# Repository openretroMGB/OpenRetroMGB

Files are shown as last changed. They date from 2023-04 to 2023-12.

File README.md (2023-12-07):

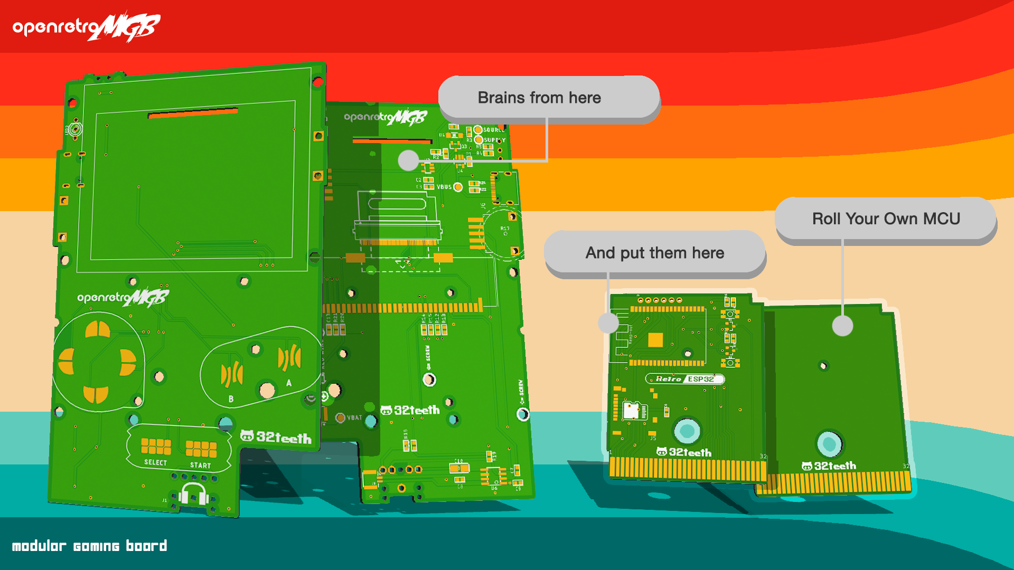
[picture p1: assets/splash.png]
Splash

> Get ready to elevate your retro gaming experience with **OpenretroMGB** - the open-source, modular gaming board that lets you customize your gameplay. Our upcoming campaign will offer exclusive rewards and perks, so don't miss out on your chance to join the retro gaming revolution. Stay tuned for more details and be part of the community that's bringing back the best of the past with the power of the future!

## Overview

**OpenretroMGB** is a new open-source ***M***odular ***G***aming ***B***oard designed for gamers and hobbyists alike. Based on the popular Retro ESP32, this compact and portable board is compatible with Game Boy Pocket form factor and allows customers to either use the prebuilt ESP32 cartridge or design their own. With an easy-to-use modular design, gamers can customize their gaming experience by swapping out cartridges that feature different games or hardware functionalities. OpenretroMGB offers an affordable and accessible way to create and enjoy retro-style games with modern features, making it perfect for enthusiasts, hobbyists, and anyone looking for a fun, retro gaming experience.

**OpenretroMGB** is certified unde Open Source Hardware as OSHWA UID [CA000028](https://certification.oshwa.org/ca000028.html) with CC-BY-SA-4.0 licensing

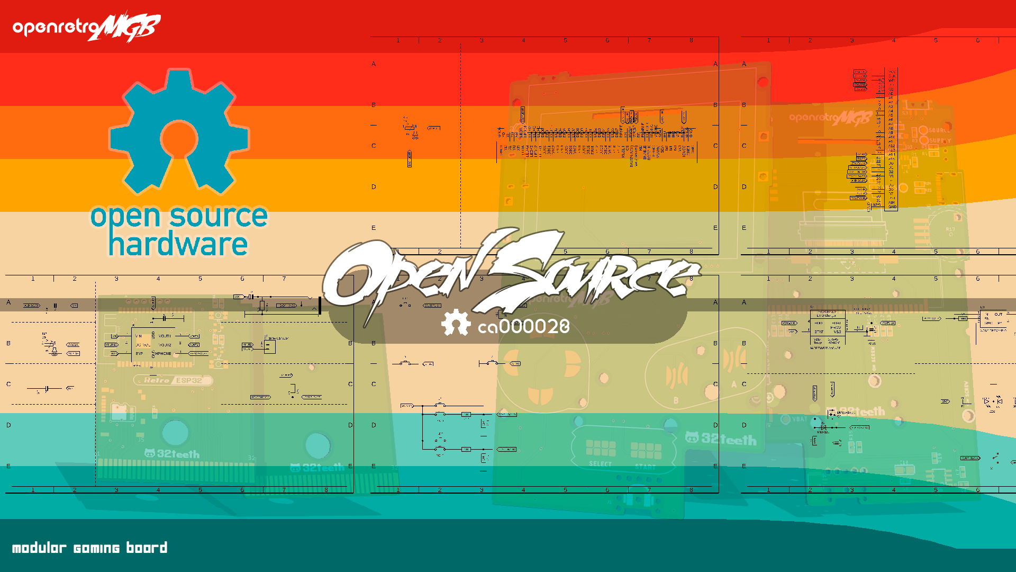
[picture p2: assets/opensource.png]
Open Source


## Features
- [x] Cartridge slot
- [x] 2.6" daylight IPS screen
- [x] Volume and brightness control
- [x] LiPo battery charging and protection circuitry
- [x] Stereo chip and headphone jack
- [x] Drop-in compatibility with Game Boy Pocket shell
- [x] Modular design
- [x] USB Data Lines
- [x] Open source

### Have your say

Join our discussions. Cast your vote in our [polls](https://github.com/openretroMGB/OpenRetroMGB/discussions/categories/polls)

## Gallery

#### Retro ESP32 Cart
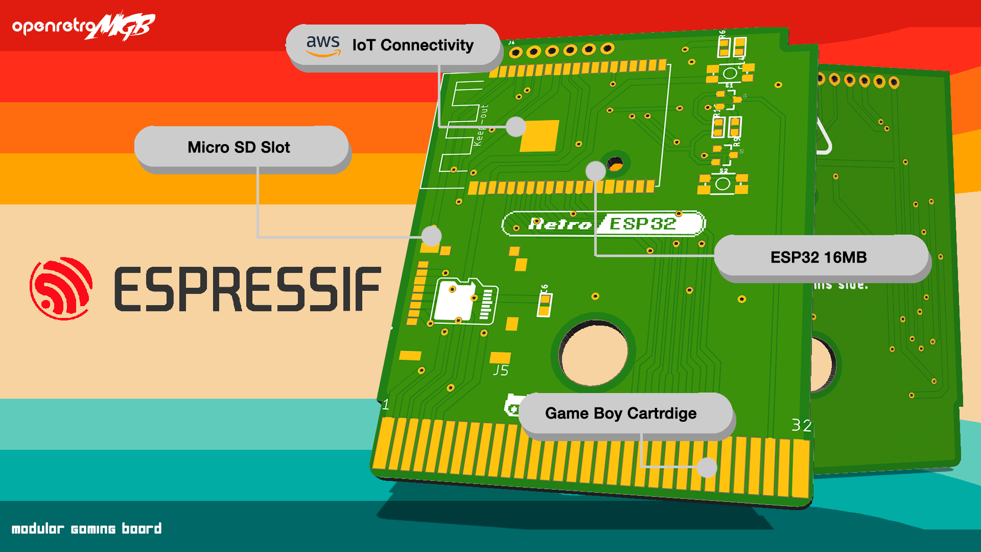
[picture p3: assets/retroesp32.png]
Retro ESP32


#### Arduino *ATmega32U4* Cart
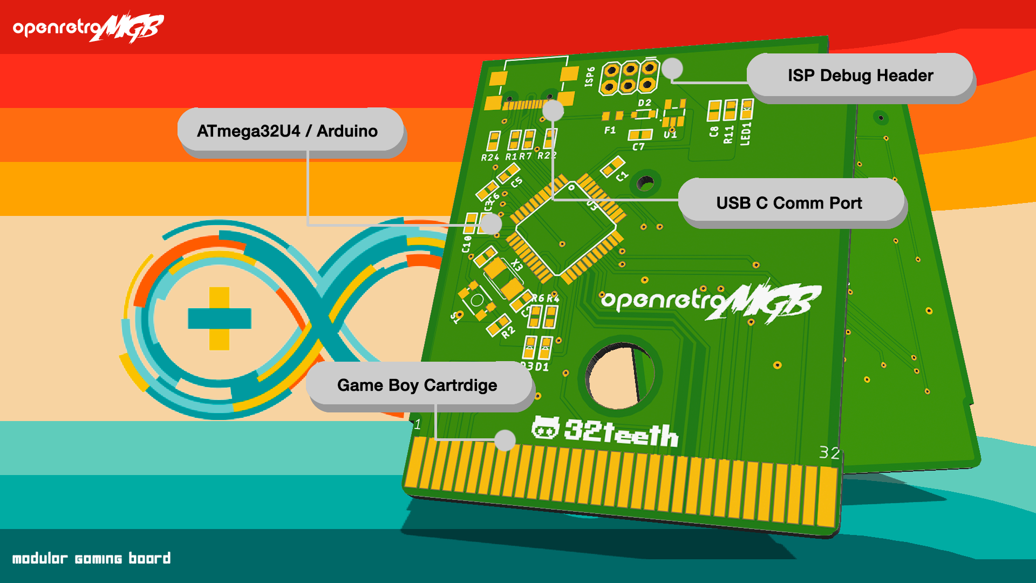
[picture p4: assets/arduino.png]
Arduino


#### USB C Data Lines
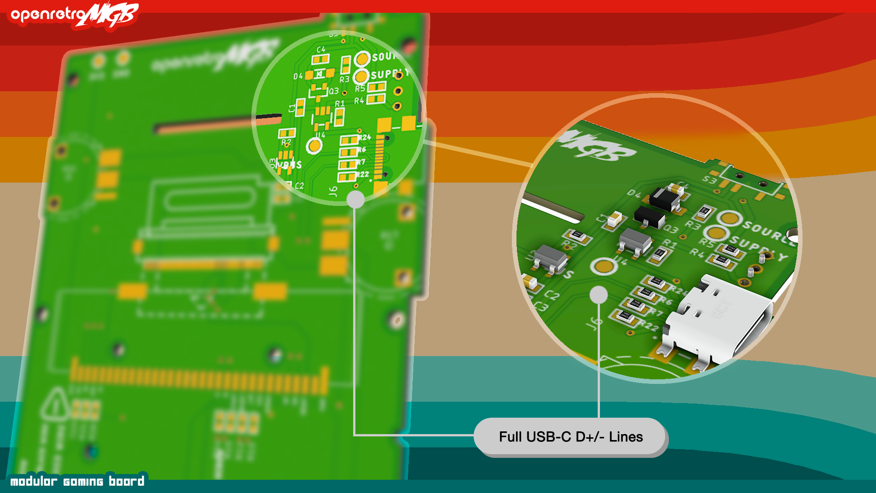
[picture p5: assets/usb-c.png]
USB


# What will you build?
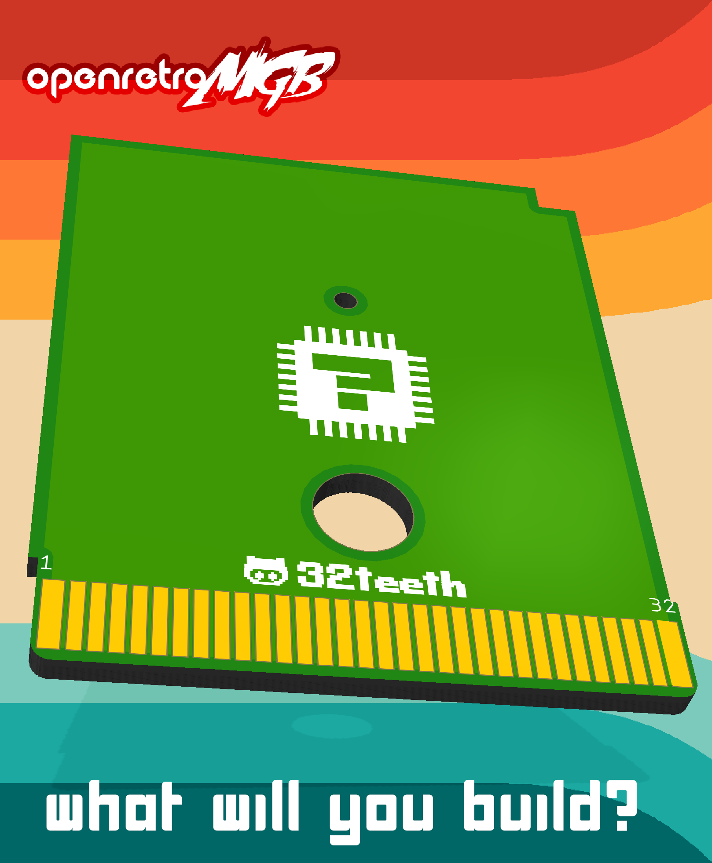
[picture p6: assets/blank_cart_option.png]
What will you build?


## Trusted Creators
> Celebrating 10 Years

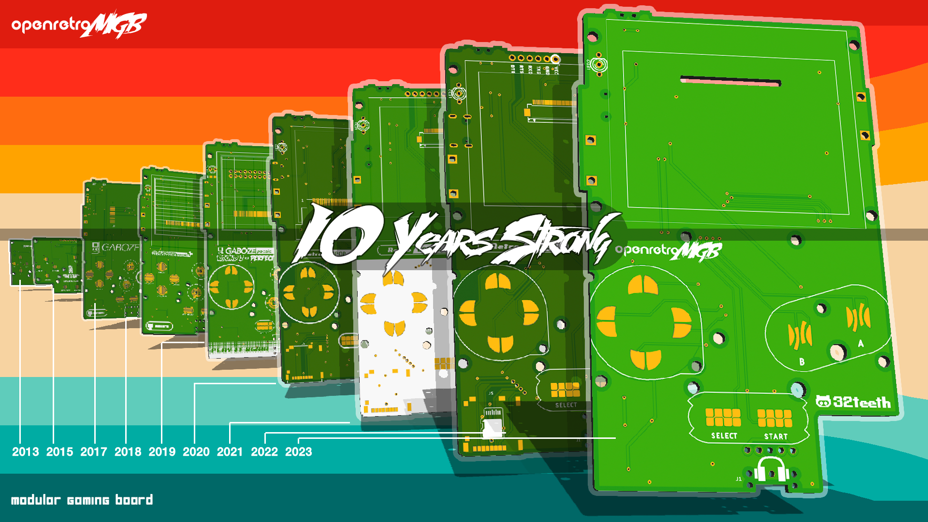
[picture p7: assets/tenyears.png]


Over the past 10 years, we have proudly established ourselves as a trusted creator and innovator in the realm of handheld retro gaming. From our early ventures with Arduino and Atmega microcontrollers to our exploration of cutting-edge technologies like ESP32 and Raspberry Pi, our journey has been driven by a relentless pursuit of innovation. With each step, we have strived to enhance the gaming experience for retro enthusiasts. Our Game Boy Pocket PCB embodies our dedication to quality, reliability, and creativity. It represents a culmination of years of expertise, resulting in a product that seamlessly blends the nostalgia of classic gaming with the power and possibilities of modern technology. As we celebrate this milestone, we extend our gratitude to our loyal customers and supporters, who have played an instrumental role in our growth and success. Looking ahead, we remain committed to pushing boundaries, embracing new advancements, and delivering unforgettable gaming experiences to enthusiasts around the world.

## Authors

* **Eugene Yevhen Andruszczenko** - *Initial and Ongoing Work* - [32teeth](https://github.com/32teeth)

### License

This project is licensed under the Creative Commons Attribution Share Alike 4.0 International - see the [LICENSE.md](LICENSE.md) file for details

## Support
> Although we do this for 💕 of 🕹️<br/>
> **We Also Like Coffee!** <br/>
> *Please Consider Supporting* <br/>

Did you know, you can support us in a few way? We offer multiple sposorship tiers, with different rewards!

Take a *look*.
See what *fits*.

 Support (https://github.com/sponsors/openretroMGB)

**Thank You**

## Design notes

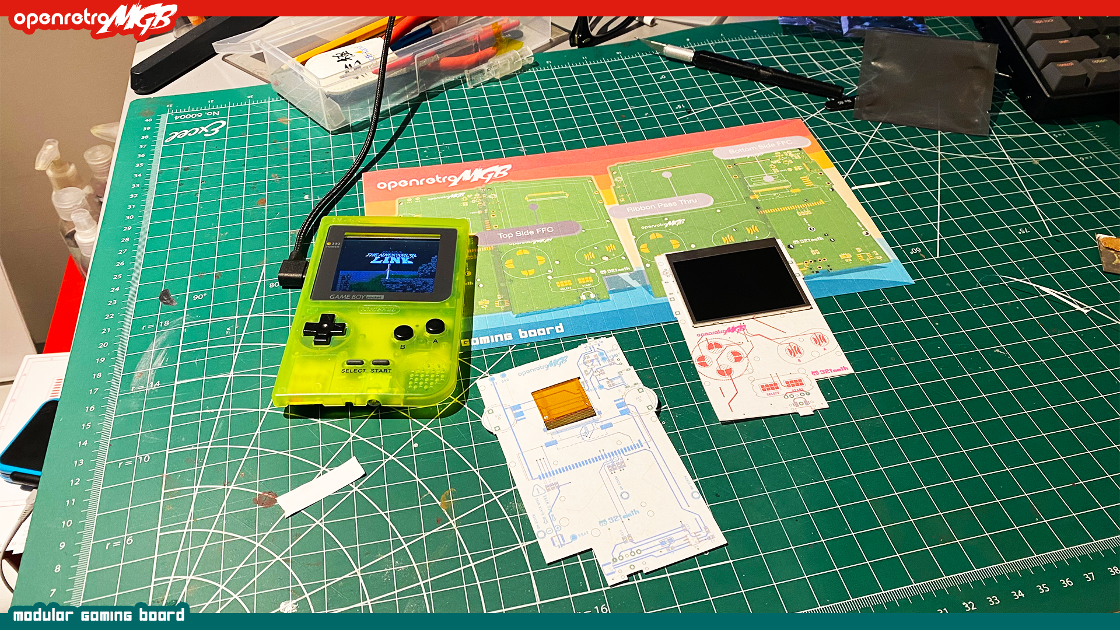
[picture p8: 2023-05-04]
assets/paper.png

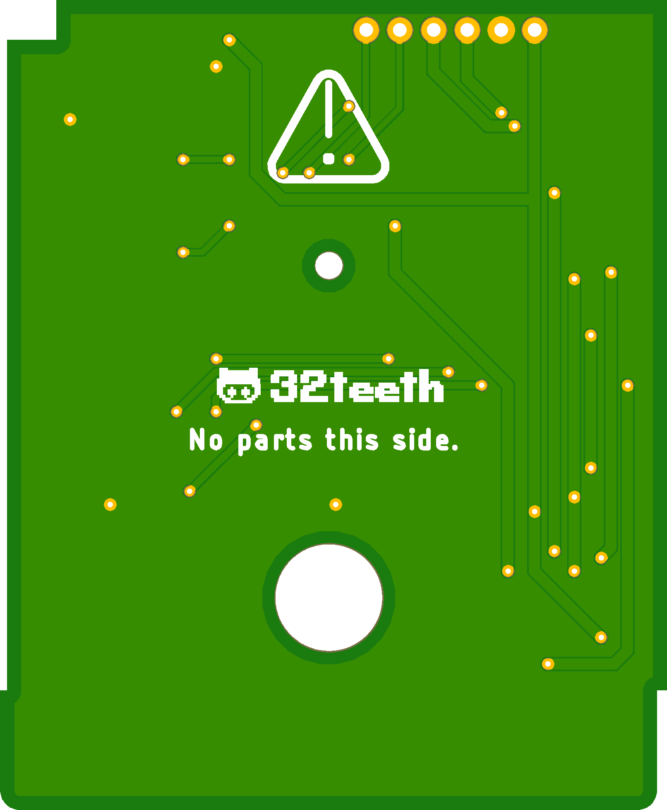
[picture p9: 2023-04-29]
assets/retro_cart_bottom.png

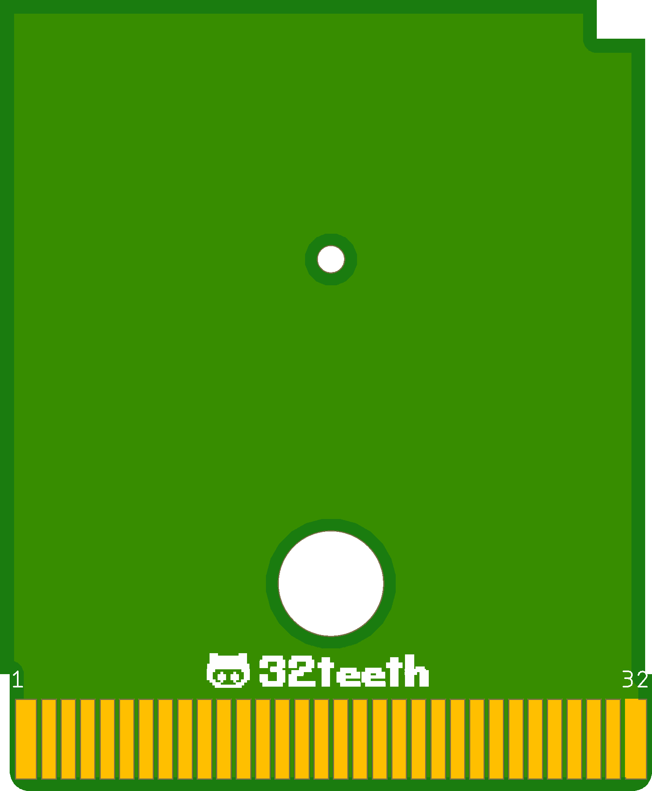
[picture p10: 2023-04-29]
assets/blank_cart_top.png

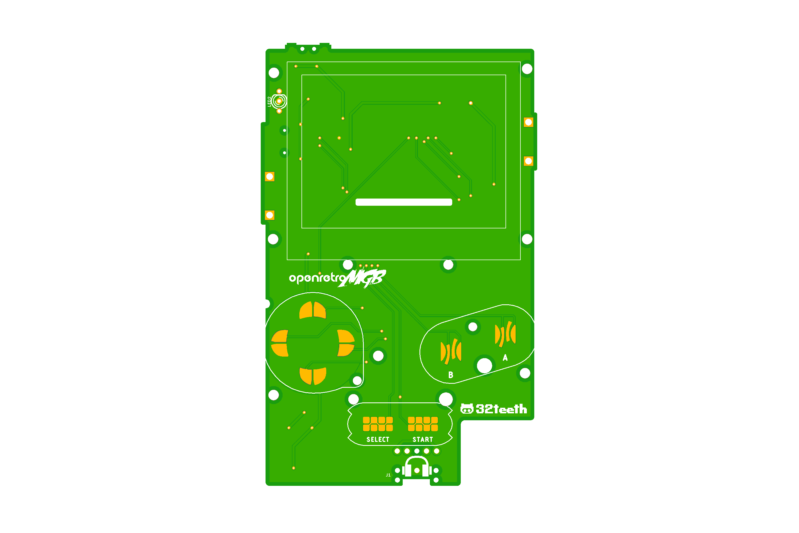
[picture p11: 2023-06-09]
assets/mainboard_new_top.png

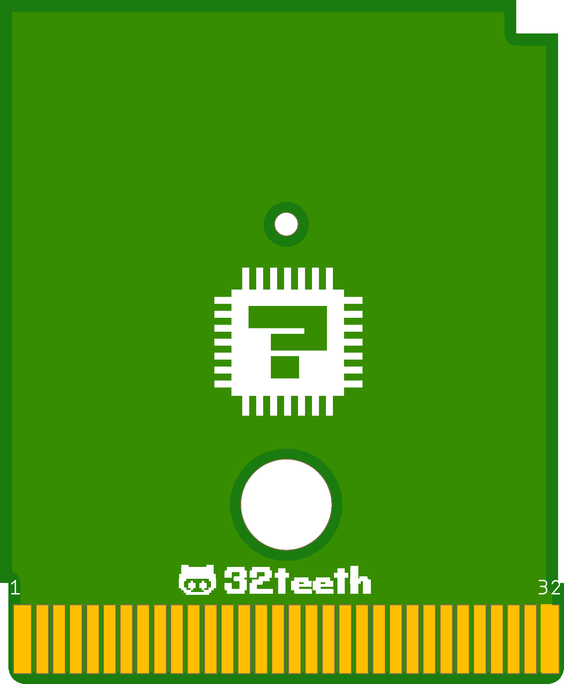
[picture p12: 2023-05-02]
assets/blank_cart_top_next.png

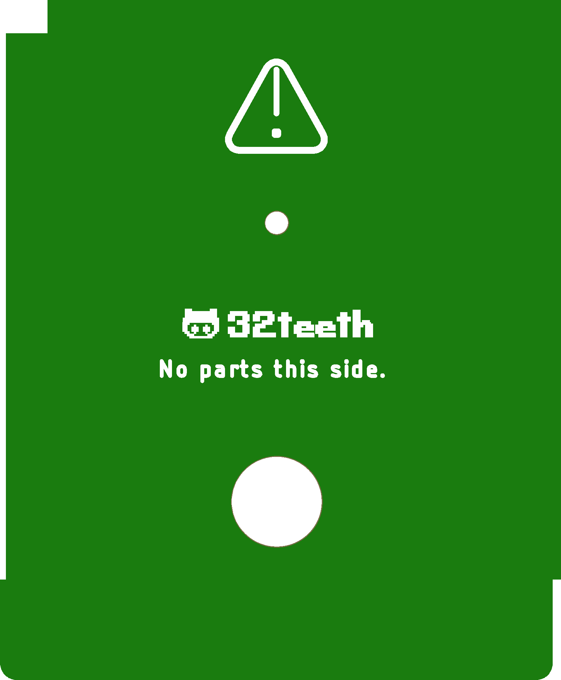
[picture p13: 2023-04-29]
assets/blank_cart_bottom.png

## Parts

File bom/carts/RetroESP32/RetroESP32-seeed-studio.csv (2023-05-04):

Qty | Designator | Package | MPN | Purchase Link
3 | R6, R9, R10 | 0603-MINI | ERJ-PA3J103V | https://www.digikey.ca/en/products/detail/panasonic-electronic-components/ERJ-PA3J103V
1 | C6 | 0603-MINI-CAP | CL10A106MP8NNNC | https://www.digikey.ca/en/products/detail/samsung-electro-mechanics/CL10A106MP8NNNC/3887529
1 | C14 | 0603-MINI-CAP | CL10A105KP8NNNC | https://www.digikey.ca/en/products/detail/samsung-electro-mechanics/CL10A105KP8NNNC/3889268
1 | J5 | 503182-1852_MOLEX_503182-1852 | 5031821852 | https://www.digikey.ca/en/products/detail/molex/5031821852/5823232
1 | U1 | ESP32-WROVER_ESP32-WROVER | ESP32-WROVER-E-N16R8 | https://www.digikey.ca/en/products/detail/espressif-systems/ESP32-WROVER-E-N16R8/11613147
2 | S1, S2 | SWITCHES_TACTILE_SWITCH_SMD_4.6X2.8MM | KMR221GLFS | https://www.digikey.ca/en/products/detail/c-k/KMR221GLFS/550472?s=N4IgTCBcDaINIFkBKYwEYDiAZAYgZRAF0BfIA
2 | Q4, Q5 | SOT23-3 | MMBT2222A-7-F | https://www.digikey.ca/en/products/detail/diodes-incorporated/MMBT2222A-7-F/814503

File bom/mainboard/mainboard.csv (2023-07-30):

Qty | Designator | Package | MPN | Purchase Link | Notes
1 | C13 | 0603-MINI-CAP | CL10B104KB8NNNC | https://www.digikey.com/en/products/detail/samsung-electro-mechanics/CL10B104KB8NNNC/3886658
5 | R2, R3, R19, R20, R21 | 0603-MINI | ERJ-PA3J104V | https://www.digikey.com/en/products/detail/panasonic-electronic-components/ERJ-PA3J104V/5035972
1 | C10 | EIA3216-18/A-W | F930J107KAA | https://www.digikey.com/en/products/detail/kyocera-avx/F930J107KAA/4005275
5 | R11, R12, R13, R14, R15 | 0603-MINI | ERJ-PA3J103V | https://www.digikey.com/en/products/detail/panasonic-electronic-components/ERJ-PA3J103V/5035971
3 | C1, C2, C4 | 0603-MINI-CAP | CL10A106MP8NNNC | https://www.digikey.com/en/products/detail/samsung-electro-mechanics/CL10A106MP8NNNC/3887529
1 | R18 | 0603-MINI | ERJ-PA3J151V | https://www.digikey.com/en/products/detail/panasonic-electronic-components/erj-p03j151v/9810793
2 | R1, R5 | 0603-MINI | ERJ-PA3J152V | https://www.digikey.com/en/products/detail/panasonic-electronic-components/erj-p03j152v/9810794
3 | C3, C8, C9 | 0603-MINI-CAP | CL10A105KP8NNNC | https://www.digikey.com/en/products/detail/samsung-electro-mechanics/CL10A105KP8NNNC/3886840
1 | C7 | 0603-MINI-CAP | CL10C221JB8NFNC | https://www.digikey.com/en/products/detail/samsung-electro-mechanics/CL10C221JB8NFNC/3890321
2 | R16, R17 | THUMBWHEEL |  | https://www.aliexpress.com/item/1005005013077311.html | Alternate: https://www.aliexpress.com/item/1005004274957084.html
1 | R4 | 0603-MINI | CRGH0603J470R | https://www.digikey.com/en/products/detail/te-connectivity-passive-product/CRGH0603J470R/2385347
2 | R6, R7 | 0603-MINI | ERJ-3EKF22R0V | https://www.digikey.ca/en/products/detail/panasonic-electronic-components/ERJ-3EKF22R0V/1746340
2 | R22, R24 | 0603-MINI | ERJ-3EKF5111V | https://www.digikey.ca/en/products/detail/panasonic-electronic-components/ERJ-3EKF5111V/198416
1 | J1 | AUDIO-JACK-KIT | SJ1-3525NG | https://www.digikey.com/en/products/detail/cui-devices/SJ1-3525NG/738690
1 | Q3 | SOT23-R | DMP2045U-7 | https://www.digikey.com/en/products/detail/diodes-incorporated/DMP2045U-7/8275359
1 | U$2 | GB-CARTRIDGE-SLOT-2 |  | https://www.aliexpress.com/item/1005004188119429.html
1 | U$11 | KD026LQTMA008-PASSTHRU | 0541044531 | https://www.digikey.ca/en/products/detail/molex/0541044531/3197022
1 | LED2 | LED_DUOLED-A-3MM | SSL-LX3059IGW | https://www.digikey.com/en/products/detail/lumex-opto-components-inc/SSL-LX3059IGW/242268
1 | U6 | SOIC8 | LM4875MX/NOPB | https://www.digikey.com/en/products/detail/texas-instruments/LM4875MX-NOPB/1871686
1 | D4 | SOD-123 | MBRX120LF-TP | digikey.com/en/products/detail/micro-commercial-co/MBRX120LF-TP/2041570
1 | U4 | SOT23-5-1 | MCP73832T-2ACI/OT | https://www.digikey.com/en/products/detail/microchip-technology/mcp73832t-2aci-ot/1223142
1 | S3 | RETIRED_KPS-1290 | MA12RTR | https://www.digikey.com/en/products/detail/apem-inc/MA12RTR
2 | X2, X3 | 53261-02 | 0532614002 | https://www.digikey.ca/en/products/detail/molex/0532614002/15622958
1 | J6 | GCT_USB4110-GF-A_REVB | USB4110-GF-A | https://www.digikey.ca/en/products/detail/gct/usb4110-gf-a/10384547
1 | U3 | SOT23-5 | XC6210B332MR-G | https://www.digikey.ca/en/products/detail/torex-semiconductor-ltd/XC6210B332MR-G/2138119
1 | N/A - This is the LCD itself |  | ET026LQTM008 | https://www.alibaba.com/product-detail/Support-Small-Quantity-2-6-inch_1600609986142.html | Alternate: https://www.aliexpress.com/item/4001077459037.html

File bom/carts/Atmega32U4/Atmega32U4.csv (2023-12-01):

Qty | Designator | Package | MPN | Purchase Link
2 | C1, C3 | 0603-MINI | CL10B104KB8NNNC | https://www.digikey.ca/en/products/detail/samsung-electro-mechanics/CL10B104KB8NNNC/3886658
3 | C5, C6, C10 | 0603-MINI-CAP | CL10A105KP8NNNC | https://www.digikey.ca/en/products/detail/samsung-electro-mechanics/CL10A105KP8NNNC/3886840
1 | R2 | 0603-MINI | ERJ-PA3J103V | https://www.digikey.ca/en/products/detail/panasonic-electronic-components/ERJ-PA3J103V/5035971
2 | C7, C8 | 0603-MINI-CAP | CL10A106MP8NNNC | https://www.digikey.ca/en/products/detail/samsung-electro-mechanics/CL10A106MP8NNNC/3887529
1 | X3 | NX5032 | NX5032GA-16.000000MHZ-LN-CD-1 | https://www.digikey.ca/en/products/detail/ndk-america-inc/NX5032GA-16-000000MHZ-LN-CD-1/1128819
3 | R4, R6, R11 | 0603-MINI | CRGH0603J1K0 | https://www.digikey.ca/en/products/detail/te-connectivity-passive-product/CRGH0603J1K0/2385355
2 | C2, C4 | 0603-MINI-CAP | CL10C220JB81PNC | https://www.digikey.ca/en/products/detail/samsung-electro-mechanics/CL10C220JB81PNC/3887884
1 | U1 | SOT23-5 | AP2112K-3.3TRG1 | https://www.digikey.ca/en/products/detail/diodes-incorporated/AP2112K-3-3TRG1/4470746
1 | U3 | TQFP44 | ATMEGA32U4RC-AU | https://www.digikey.ca/en/products/detail/microchip-technology/ATMEGA32U4RC-AU/2507982
1 | D2 | SOD-323 | PMEG1030EJ,115 | https://www.digikey.ca/en/products/detail/nexperia-usa-inc/PMEG1030EJ-115/1157660
2 | R1, R7 | 0603-MINI | ERJ-3EKF22R0V | https://www.digikey.ca/en/products/detail/panasonic-electronic-components/ERJ-3EKF22R0V/1746340
2 | R22, R24 | 0603-MINI | ERJ-PA3F5101V | https://www.digikey.ca/en/products/detail/panasonic-electronic-components/ERJ-PA3F5101V/5035934
1 | F1 | 1206 | PTS12066V050 | https://www.digikey.ca/en/products/detail/eaton-electronics-division/PTS12066V050/2639136
3 | D1, D3, LED1 | CHIPLED_0603 | SML-LX0603GW-TR | https://www.digikey.ca/en/products/detail/lumex-opto-components-inc/SML-LX0603GW-TR/304359
1 | S1 | TACTILE_SWITCH_SMD_4.6X2.8MM | KMR221GLFS | https://www.digikey.ca/en/products/detail/c-k/KMR221GLFS/550472
1 | J6 | GCT_USB4110-GF-A_REVB | USB4110-GF-A | https://www.digikey.ca/en/products/detail/gct/USB4110-GF-A/10384547

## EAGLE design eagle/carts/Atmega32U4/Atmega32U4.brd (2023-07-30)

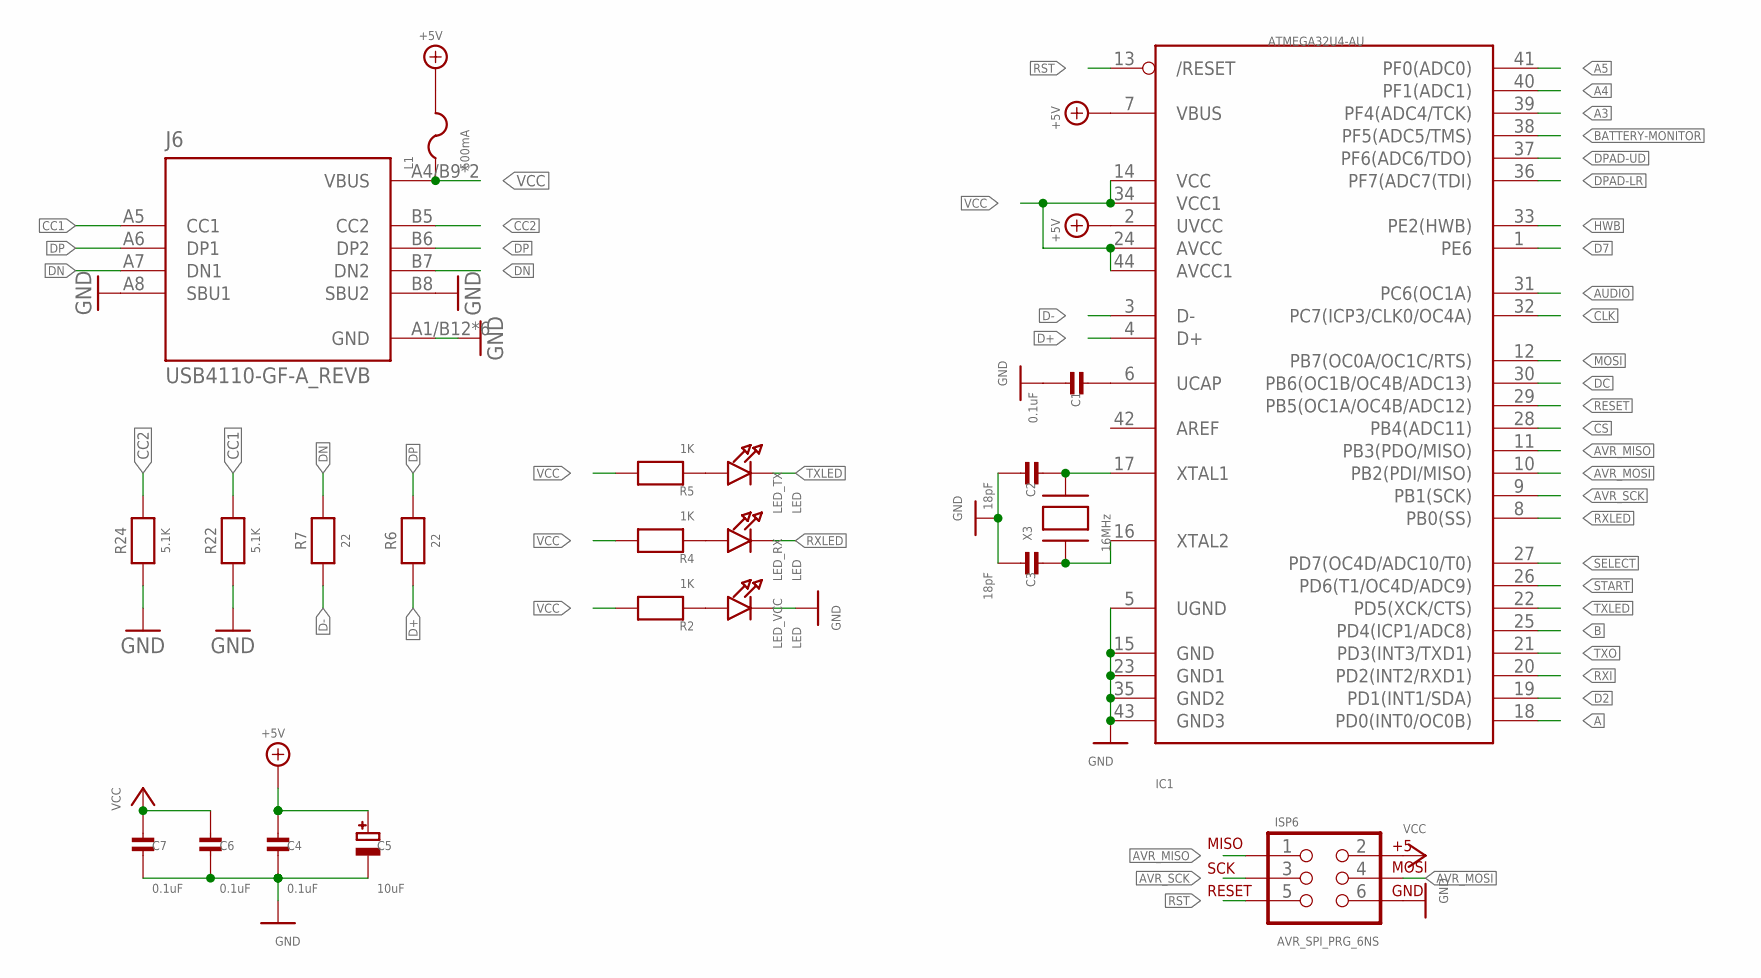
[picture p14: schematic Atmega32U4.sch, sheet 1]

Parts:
C1, C4, C6, C7: 0.1uF; 0603-MINI-CAP
C2, C3: 18pF; 0603-MINI-CAP
C5: 10uF; EIA3216-18/A-W
IC1: ATMEGA32U4-AU; TQFP44
ISP6: AVR_SPI_PRG_6NS; 2X3-NS
J6: USB4110-GF-A_REVB; GCT_USB4110-GF-A_REVB; MPN USB4105-GF-A
L1: 500mA; R1206
LED_RX: LED; CHIPLED_0603
LED_TX: LED; CHIPLED_0603
LED_VCC: LED; CHIPLED_0603
R2, R4, R5: 1K; 0603-MINI
R6, R7: 22; 0603-MINI; MPN ERJ-3EKF22R0V
R22, R24: 5.1K; 0603-MINI; MPN ERJ-PA3F5101V
X3: 16MHz; NX5032

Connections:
+5V: C4.1, C5.+, IC1.2 (UVCC), IC1.7 (VBUS), L1.2
A: IC1.18 (PD0(INT0/OC0B)); also elsewhere on the board
A3: IC1.39 (PF4(ADC4/TCK))
A4: IC1.40 (PF1(ADC1))
A5: IC1.41 (PF0(ADC0))
AUDIO: IC1.31 (PC6(OC1A)); also elsewhere on the board
AVR_MISO: IC1.11 (PB3(PDO/MISO)), ISP6.1
AVR_MOSI: IC1.10 (PB2(PDI/MISO)), ISP6.4
AVR_SCK: IC1.9 (PB1(SCK)), ISP6.3
B: IC1.25 (PD4(ICP1/ADC8)); also elsewhere on the board
BATTERY-MONITOR: IC1.38 (PF5(ADC5/TMS)); also elsewhere on the board
CC1: J6.A5 (CC1), R22.2
CC2: J6.B5 (CC2), R24.2
CLK: IC1.32 (PC7(ICP3/CLK0/OC4A)); also elsewhere on the board
CS: IC1.28 (PB4(ADC11)); also elsewhere on the board
D2: IC1.19 (PD1(INT1/SDA))
D7: IC1.1 (PE6)
D+: IC1.4 (D+), R6.1
D-: IC1.3 (D-), R7.1
DC: IC1.30 (PB6(OC1B/OC4B/ADC13)); also elsewhere on the board
DN: J6.A7 (DN1), J6.B7 (DN2), R7.2
DP: J6.A6 (DP1), J6.B6 (DP2), R6.2
DPAD-LR: IC1.36 (PF7(ADC7(TDI)); also elsewhere on the board
DPAD-UD: IC1.37 (PF6(ADC6/TDO)); also elsewhere on the board
GND: C1.2, C2.2, C3.2, C4.2, C5.-, C6.2, C7.2, IC1.5 (UGND), IC1.15 (GND), IC1.23 (GND1), IC1.35 (GND2), IC1.43 (GND3), ISP6.6, J6.A1/B12 (GND), J6.A8 (SBU1), J6.B1/A12 (GND), J6.B8 (SBU2), J6.S1 (GND), J6.S2 (GND), J6.S3 (GND), J6.S4 (GND), LED_VCC.C, R22.1, R24.1; also elsewhere on the board
HWB: IC1.33 (PE2(HWB))
MOSI: IC1.12 (PB7(OC0A/OC1C/RTS)); also elsewhere on the board
unnamed: LED_VCC.A, R2.1
unnamed: C1.1, IC1.6 (UCAP)
unnamed: LED_RX.A, R4.1
unnamed: LED_TX.A, R5.1
unnamed: C2.1, IC1.17 (XTAL1), X3.P$2
unnamed: C3.1, IC1.16 (XTAL2), X3.P$1
RESET: IC1.29 (PB5(OC1A/OC4B/ADC12)); also elsewhere on the board
RST: IC1.13 (/RESET), ISP6.5
RXI: IC1.20 (PD2(INT2/RXD1))
RXLED: IC1.8 (PB0(SS)), LED_RX.C
SELECT: IC1.27 (PD7(OC4D/ADC10/T0)); also elsewhere on the board
START: IC1.26 (PD6(T1/OC4D/ADC9)); also elsewhere on the board
TXLED: IC1.22 (PD5(XCK/CTS)), LED_TX.C
TXO: IC1.21 (PD3(INT3/TXD1))
VCC: C6.1, C7.1, IC1.14 (VCC), IC1.24 (AVCC), IC1.34 (VCC1), IC1.44 (AVCC1), ISP6.2, J6.A4/B9 (VBUS), J6.B4/A9 (VBUS), L1.1, R2.2, R4.2, R5.2; also elsewhere on the board

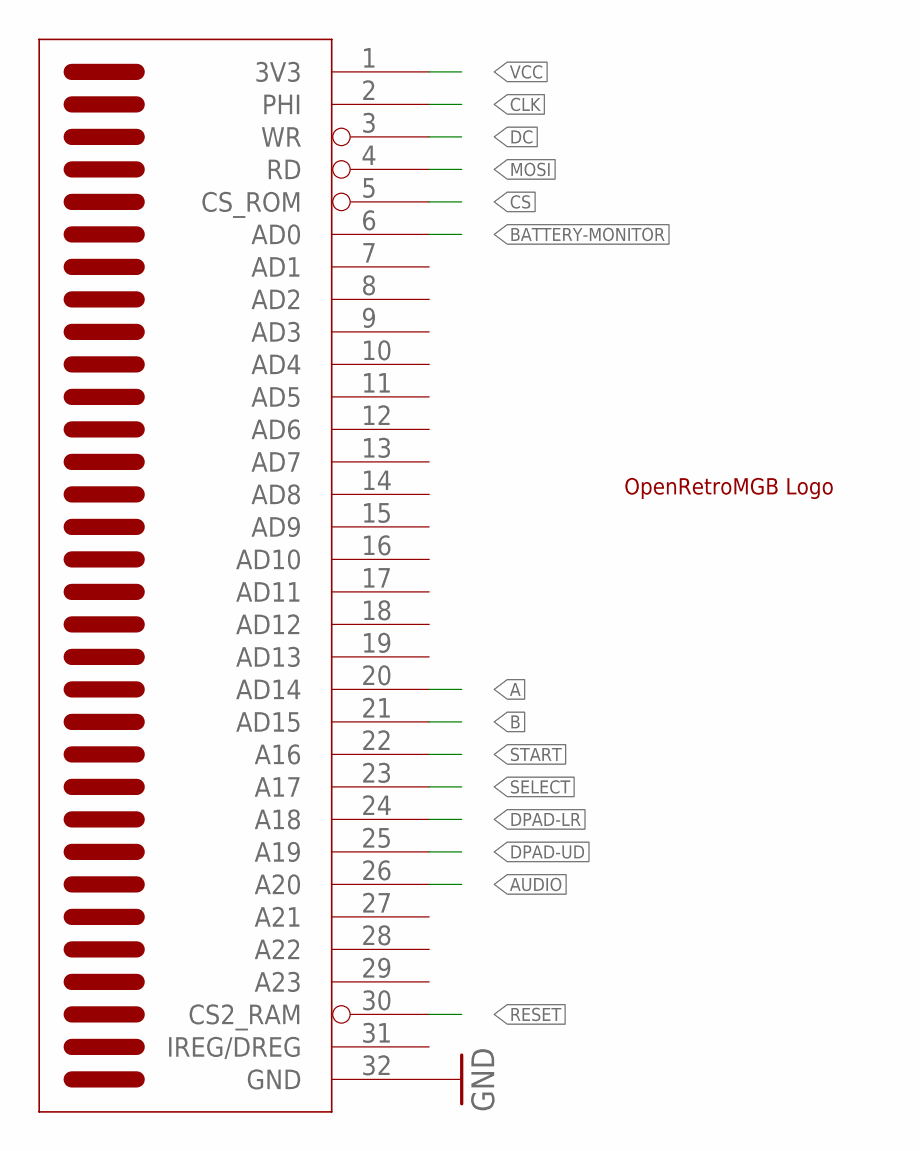
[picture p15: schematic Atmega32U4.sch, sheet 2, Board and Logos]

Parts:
U$1: OPENRETROMGB; OPENRETROMBG
U$2: GBA_CARTLARGE; GBCART

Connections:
A: U$2.20 (AD14); also elsewhere on the board
AUDIO: U$2.26 (A20); also elsewhere on the board
B: U$2.21 (AD15); also elsewhere on the board
BATTERY-MONITOR: U$2.6 (AD0); also elsewhere on the board
CLK: U$2.2 (PHI); also elsewhere on the board
CS: U$2.5 (CS_ROM); also elsewhere on the board
DC: U$2.3 (WR); also elsewhere on the board
DPAD-LR: U$2.24 (A18); also elsewhere on the board
DPAD-UD: U$2.25 (A19); also elsewhere on the board
GND: U$2.32 (GND); also elsewhere on the board
MOSI: U$2.4 (RD); also elsewhere on the board
RESET: U$2.30 (CS2_RAM); also elsewhere on the board
SELECT: U$2.23 (A17); also elsewhere on the board
START: U$2.22 (A16); also elsewhere on the board
VCC: U$2.1 (3V3); also elsewhere on the board

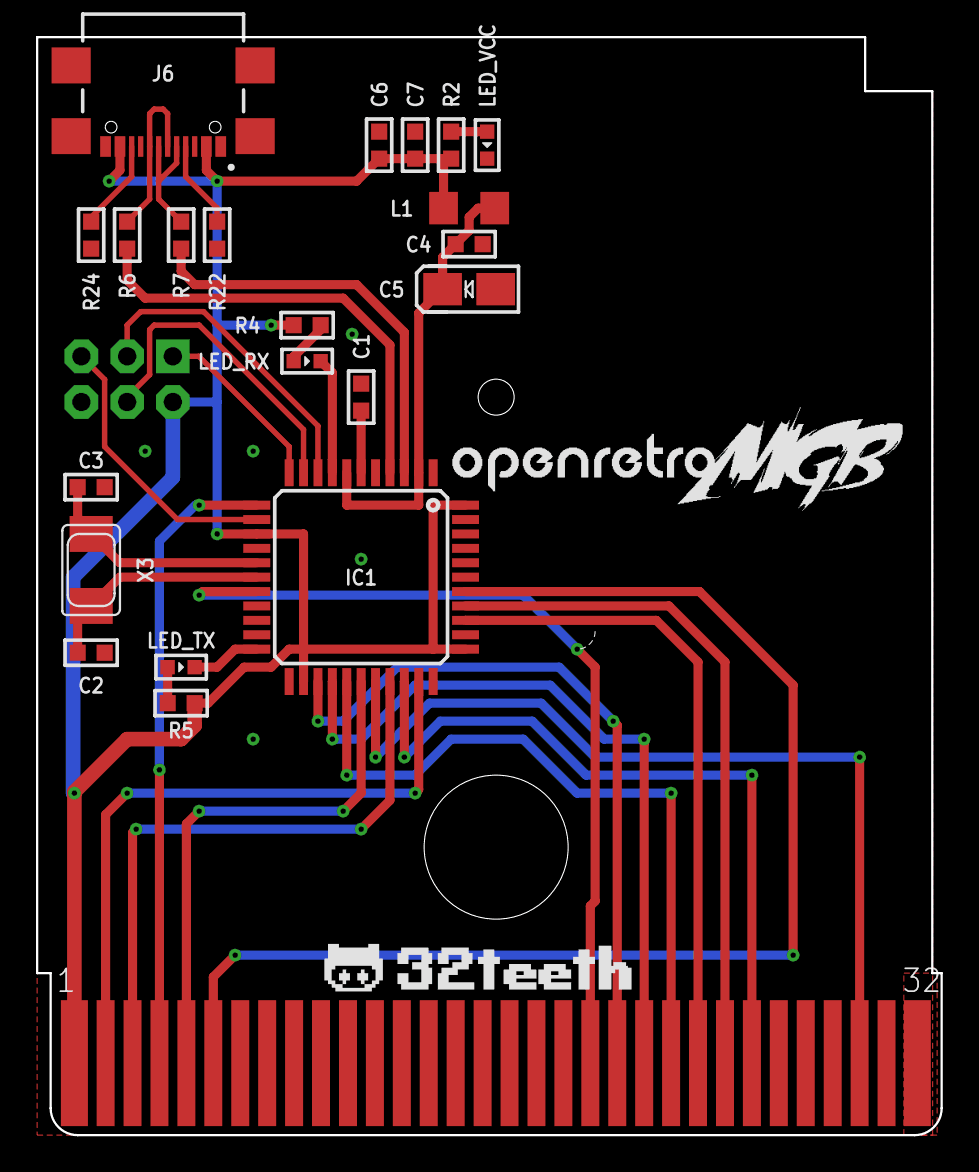
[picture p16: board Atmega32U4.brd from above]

Board: 2 copper layers, 50.2 x 61.0 mm, 24 parts (0 on the bottom side), 34 nets.

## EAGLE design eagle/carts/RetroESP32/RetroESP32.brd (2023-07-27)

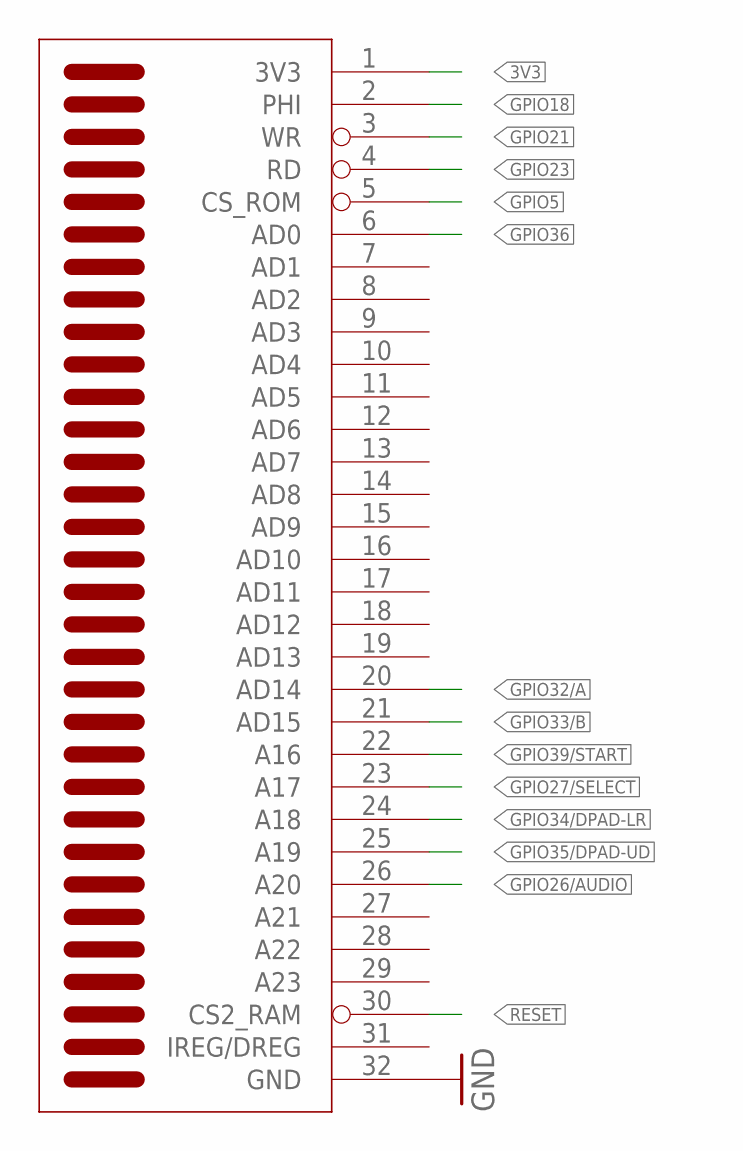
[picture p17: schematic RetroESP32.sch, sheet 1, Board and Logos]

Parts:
U$2: GBA_CARTLARGE; GBCART

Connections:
3V3: U$2.1 (3V3); also elsewhere on the board
GND: U$2.32 (GND); also elsewhere on the board
GPIO5: U$2.5 (CS_ROM); also elsewhere on the board
GPIO18: U$2.2 (PHI); also elsewhere on the board
GPIO21: U$2.3 (WR); also elsewhere on the board
GPIO23: U$2.4 (RD); also elsewhere on the board
GPIO26/AUDIO: U$2.26 (A20); also elsewhere on the board
GPIO27/SELECT: U$2.23 (A17); also elsewhere on the board
GPIO32/A: U$2.20 (AD14); also elsewhere on the board
GPIO33/B: U$2.21 (AD15); also elsewhere on the board
GPIO34/DPAD-LR: U$2.24 (A18); also elsewhere on the board
GPIO35/DPAD-UD: U$2.25 (A19); also elsewhere on the board
GPIO36: U$2.6 (AD0); also elsewhere on the board
GPIO39/START: U$2.22 (A16); also elsewhere on the board
RESET: U$2.30 (CS2_RAM); also elsewhere on the board

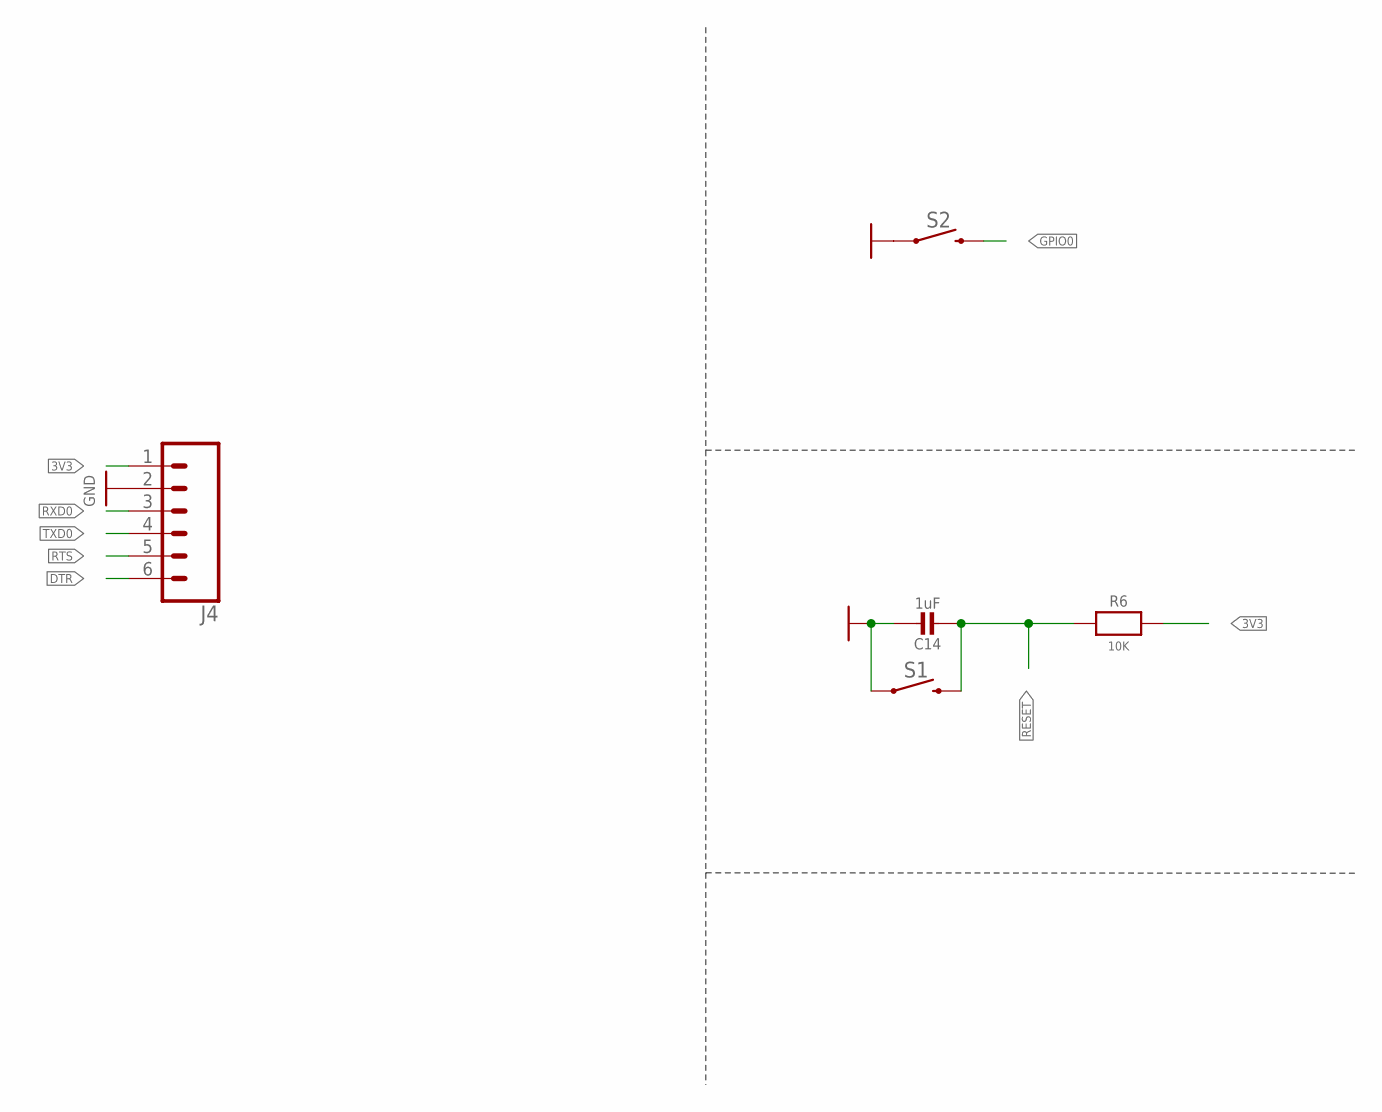
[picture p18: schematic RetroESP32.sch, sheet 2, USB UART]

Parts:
C14: 1uF; 0603-MINI-CAP; MPN CL10A105KP8NNNC
J4: CONN_06NO_SILK_NO_POP; 1X06_NO_SILK
R6: 10K; 0603-MINI; MPN ERJ-PA3J103V
S1, S2: SWITCHES_MOMENTARY-SWITCH-SPST-SMD-4.6X2.8MM; SWITCHES_TACTILE_SWITCH_SMD_4.6X2.8MM; MPN KMR221GLFS

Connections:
3V3: J4.1, R6.2; also elsewhere on the board
DTR: J4.6; also elsewhere on the board
GND: C14.1, J4.2, S1.1, S1.2 (1), S2.1, S2.2 (1); also elsewhere on the board
GPIO0: S2.3 (2), S2.4 (2); also elsewhere on the board
RESET: C14.2, R6.1, S1.3 (2), S1.4 (2); also elsewhere on the board
RTS: J4.5; also elsewhere on the board
RXD0: J4.3; also elsewhere on the board
TXD0: J4.4; also elsewhere on the board

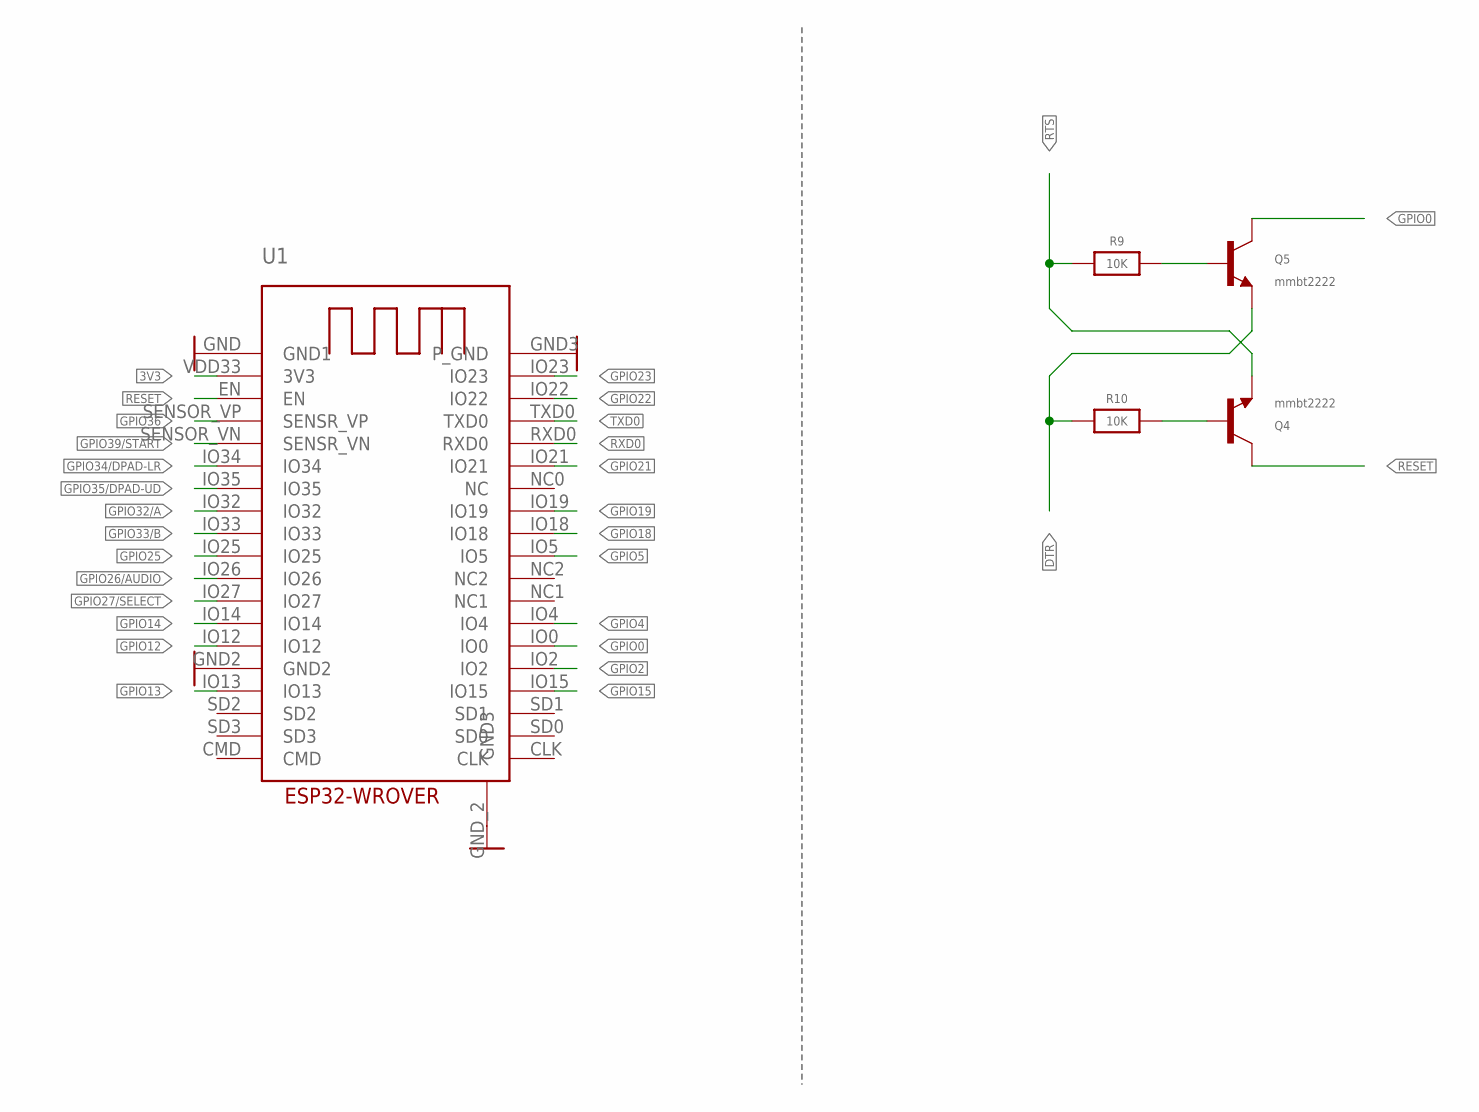
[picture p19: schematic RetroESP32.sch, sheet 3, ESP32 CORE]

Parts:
Q4, Q5: mmbt2222; SOT23-3; MPN MMBT2222A-7-F
R9, R10: 10K; 0603-MINI; MPN ERJ-PA3J103V
U1: ESP32-WROVER_ESP32-WROVER; MPN ESP32-WROVER (16MB)

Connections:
3V3: U1.VDD33 (3V3); also elsewhere on the board
DTR: Q5.2 (E), R10.1; also elsewhere on the board
GND: U1.GND (GND1), U1.GND2, U1.GND3 (P_GND), U1.GND_2 (GND3); also elsewhere on the board
GPIO0: Q5.3 (C), U1.IO0; also elsewhere on the board
GPIO2: U1.IO2
GPIO4: U1.IO4
GPIO5: U1.IO5; also elsewhere on the board
GPIO12: U1.IO12
GPIO13: U1.IO13
GPIO14: U1.IO14
GPIO15: U1.IO15
GPIO18: U1.IO18; also elsewhere on the board
GPIO19: U1.IO19; also elsewhere on the board
GPIO21: U1.IO21; also elsewhere on the board
GPIO22: U1.IO22; also elsewhere on the board
GPIO23: U1.IO23; also elsewhere on the board
GPIO25: U1.IO25
GPIO26/AUDIO: U1.IO26; also elsewhere on the board
GPIO27/SELECT: U1.IO27; also elsewhere on the board
GPIO32/A: U1.IO32; also elsewhere on the board
GPIO33/B: U1.IO33; also elsewhere on the board
GPIO34/DPAD-LR: U1.IO34; also elsewhere on the board
GPIO35/DPAD-UD: U1.IO35; also elsewhere on the board
GPIO36: U1.SENSOR_VP (SENSR_VP); also elsewhere on the board
GPIO39/START: U1.SENSOR_VN (SENSR_VN); also elsewhere on the board
RESET: Q4.3 (C), U1.EN; also elsewhere on the board
RST-RES: Q4.1 (B), R10.2
RTS: Q4.2 (E), R9.1; also elsewhere on the board
RTS-RES: Q5.1 (B), R9.2
RXD0: U1.RXD0; also elsewhere on the board
TXD0: U1.TXD0; also elsewhere on the board

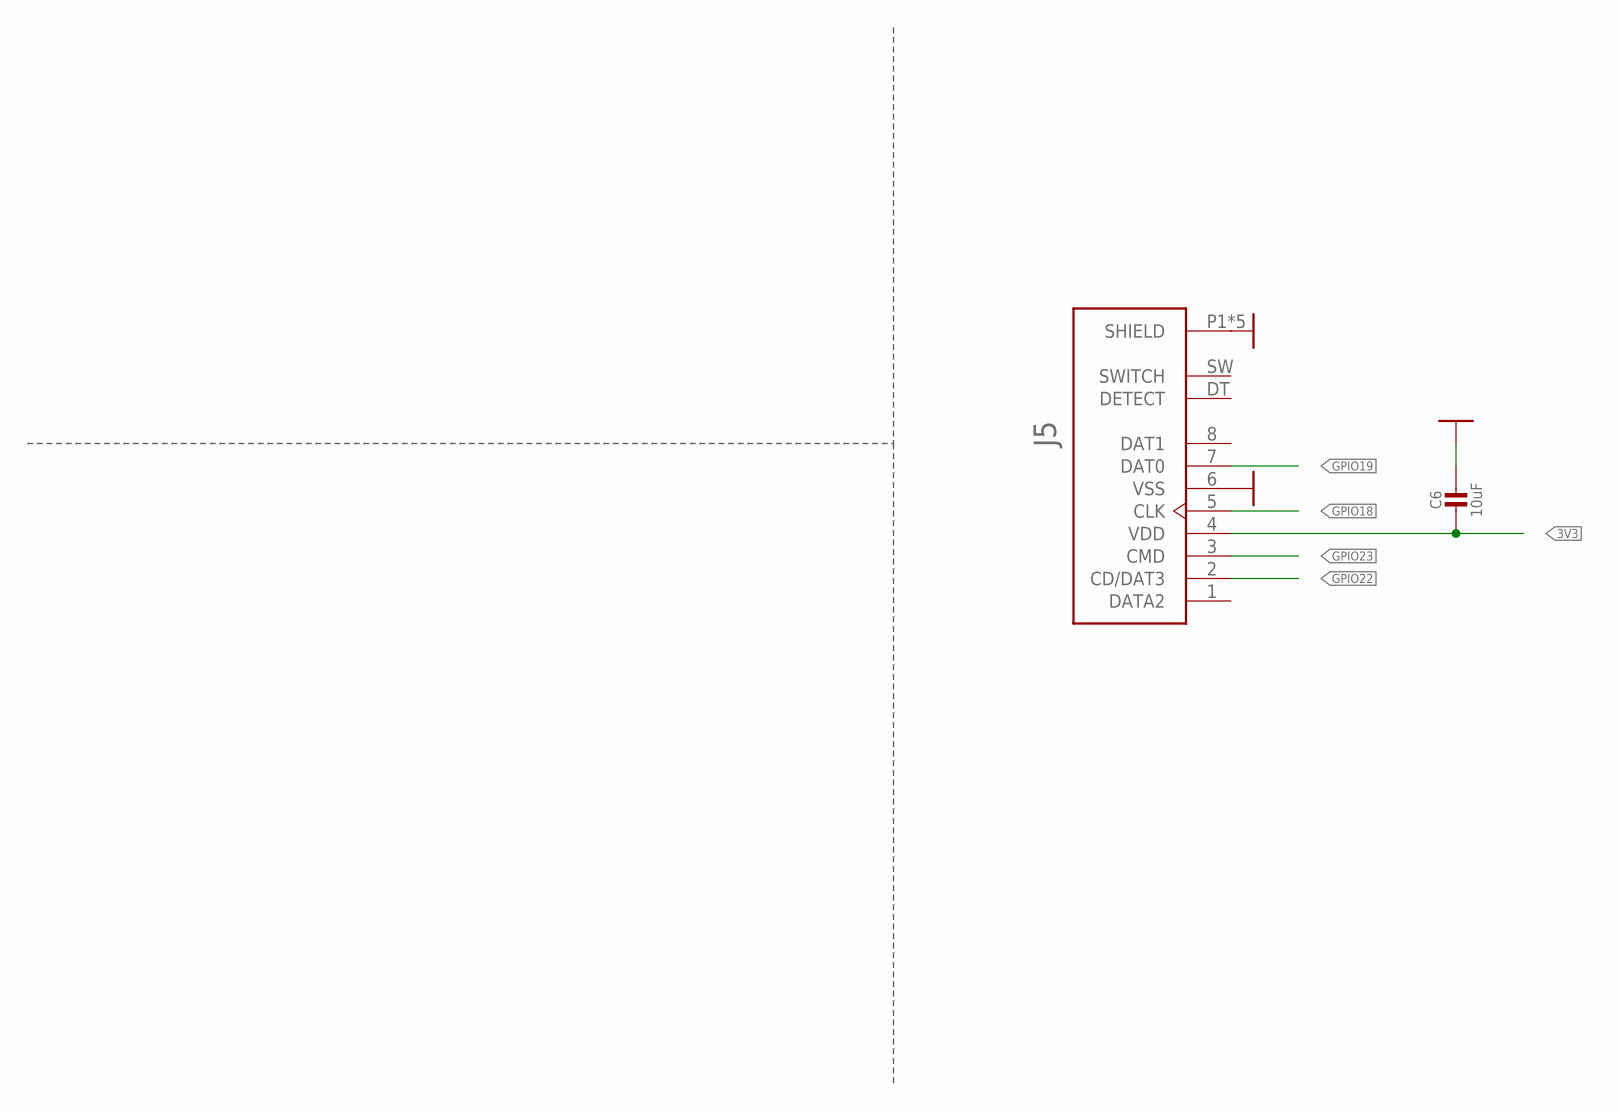
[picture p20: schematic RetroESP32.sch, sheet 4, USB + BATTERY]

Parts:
C6: 10uF; 0603-MINI-CAP; MPN CL10A106MP8NNNC
J5: 503182-1852_503182-1852; 503182-1852_MOLEX_503182-1852; MPN 5031821852

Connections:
3V3: C6.2, J5.4 (VDD); also elsewhere on the board
GND: C6.1, J5.6 (VSS), J5.P1 (SHIELD), J5.P2 (SHIELD), J5.P3 (SHIELD), J5.P4 (SHIELD), J5.P5 (SHIELD); also elsewhere on the board
GPIO18: J5.5 (CLK); also elsewhere on the board
GPIO19: J5.7 (DAT0); also elsewhere on the board
GPIO22: J5.2 (CD/DAT3); also elsewhere on the board
GPIO23: J5.3 (CMD); also elsewhere on the board

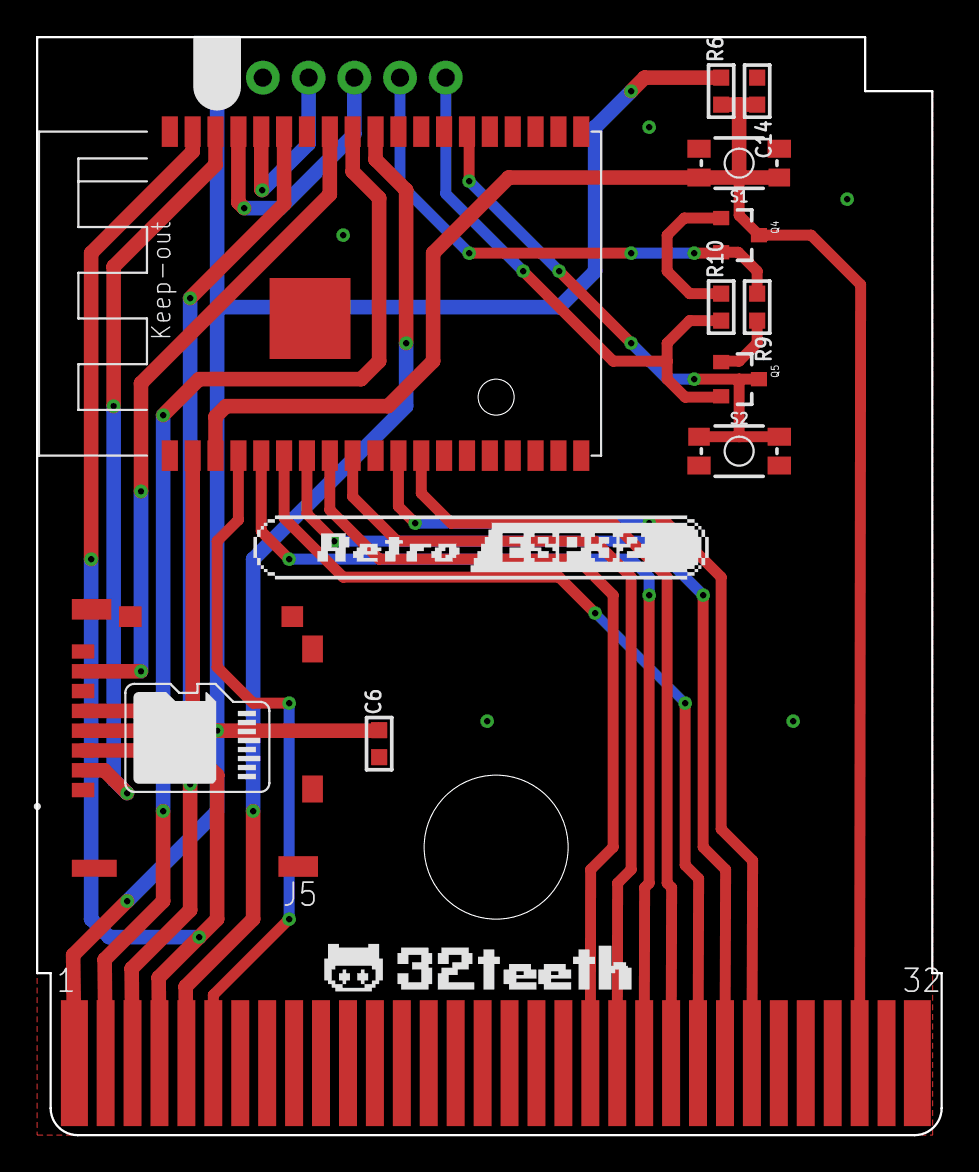
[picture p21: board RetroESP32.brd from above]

Board: 2 copper layers, 50.2 x 61.0 mm, 13 parts (0 on the bottom side), 24 nets.

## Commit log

2023-04-28 Initial Commit - The one that started it all
    [OpenRetroMGB.brd, OpenRetroMGB.cart.brd, OpenRetroMGB.cart.sch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]
2023-04-29 feat: README and assets
    [OpenRetroMGB.brd, OpenRetroMGB.sch]
2023-04-29 fix: ignore files
    [OpenRetroMGB.brd, OpenRetroMGB.cart.brd, OpenRetroMGB.cart.sch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]
2023-05-02 feat: added slotted mainboard for passthru lcd ribbon
2023-05-03 feat: added BOM for mainboard
    [mainboard-pass-thru.csv]
2023-05-04 feat: added bill of materials
    [RetroESP32.csv, mainboard-pass-thru.csv]
2023-05-04 fix: naming for bom and gerbers
    [RetroESP32.csv, mainboard.csv]
2023-05-04 feat: USB C - Lines
    [mainboard.csv]
2023-05-12 feat: Atmega32u4 image and BOM
    [Atmega32U4.csv, mainboard-seeed-studio.csv]
2023-05-12 feat: retro esp32 image
2023-05-14 feat: added links to 32u4 bom
    [Atmega32U4.csv]
2023-05-18 feat: ten years
    [Atmega32U4-seeed-studio.csv, RetroESP32-seeed-studio.csv]
2023-05-19 feat: added slim csv bom for mainboard
    [mainboard-fpc-usb-only.csv]
2023-05-19 feat: removed unsourcable parts from seeed studio mainboard
    [mainboard-seeed-studio.csv]
2023-05-19 feat: added interactive PCB for mainboard
2023-05-19 feat: added interactive bom for retroesp32 cart
2023-06-09 feat: quick asset update
    [mainboard-seeed-studio.csv]
2023-06-14 feat: 32u4 full release
    [Atmega32U4.brd, Atmega32U4.sch]
2023-06-14 feat: update JST to Molex connector
    [mainboard-seeed-studio.csv, mainboard.csv]
2023-06-27 feat: updated U$11 component
    [mainboard-fpc-usb-only.csv, mainboard-seeed-studio.csv, mainboard.csv]
2023-07-02 feat: release cartridge OSH
    [Atmega32U4.brd, RetroESP32.brd, RetroESP32.sch]
2023-07-03 feat: update Atmega32u4
    [Atmega32U4.brd, Atmega32U4.sch]
2023-07-09 feat: update board
    [RetroESP32.brd, RetroESP32.sch]
2023-07-10 feat: tighter d-pad
    [Atmega32U4.brd, Atmega32U4.sch, RetroESP32.brd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]
2023-07-27 feat: update USB and VCC lines on ATMega
    [Atmega32U4-seeed-studio.csv, Atmega32U4.brd, Atmega32U4.csv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]
2023-07-30 feat: redesign ATmega cartridge
    [Atmega32U4.brd, Atmega32U4.sch, mainboard.csv]

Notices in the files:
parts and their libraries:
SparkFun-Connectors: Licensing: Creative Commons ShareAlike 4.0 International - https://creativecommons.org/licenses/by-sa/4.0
